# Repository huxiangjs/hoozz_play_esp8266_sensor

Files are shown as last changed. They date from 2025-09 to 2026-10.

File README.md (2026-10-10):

# Hoozz Play ESP8266 Sensor

Various sensors



## Sensor List

### (1) Temperature/Humidity/Brightness Sensor
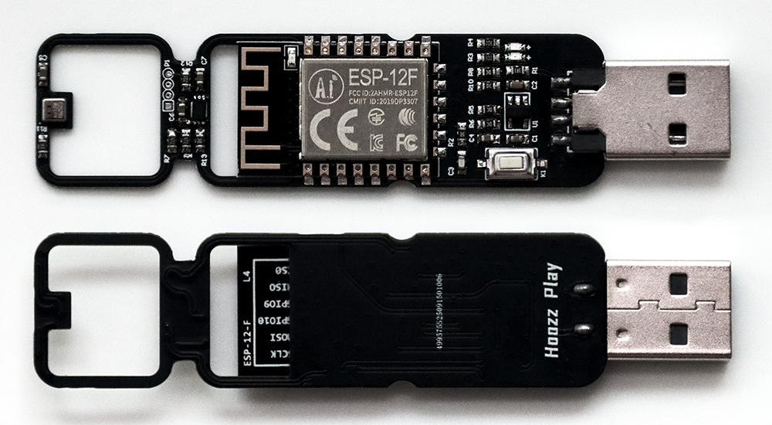
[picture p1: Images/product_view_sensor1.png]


### (2) tVOC/CO2eq Sensor
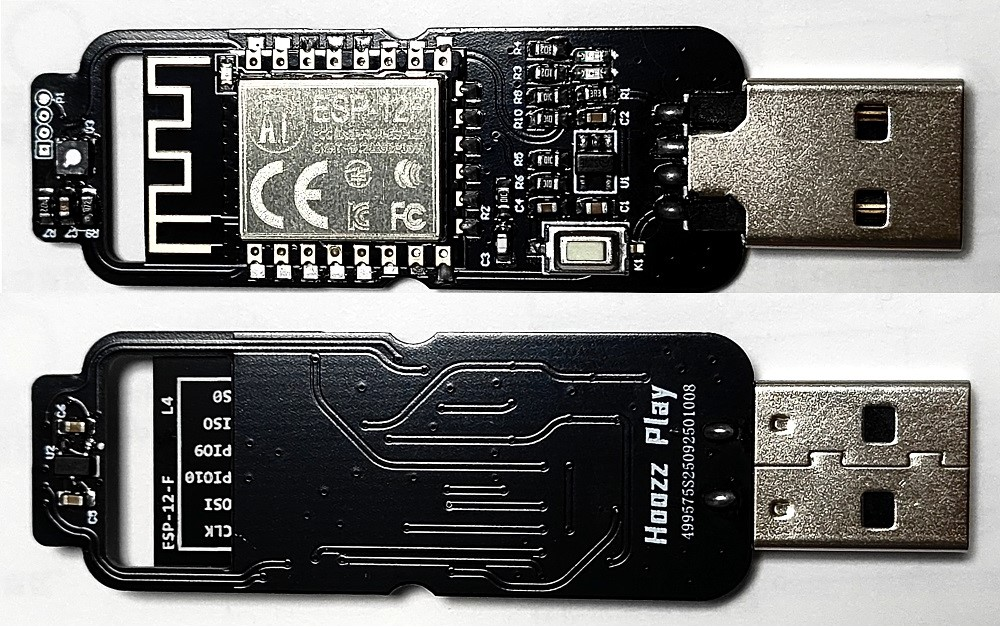
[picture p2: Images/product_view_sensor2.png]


## ESP8266_RTOS_SDK Version
```shell
$ git branch
* release/v3.3

$ git log --oneline | head -n 3
2bc42667 Merge branch 'bugfix/constrain_cryptography_v3.3' into 'release/v3.3'
4cab385e Tools: Constrain the cryptography package for avoiding breaking changes
6c438bce Merge branch 'bugfix/queue_arith_overflow_v3.3' into 'release/v3.3'

Toolchain version: crosstool-ng-1.22.0-100-ge567ec7b
Compiler version: 5.2.0
```

## Pull source code
```shell
git clone https://github.com/huxiangjs/hoozz_play_esp8266_sensor.git --recurse-submodules
```

## Build and Flash

* first step: open the sdkconfig file, modify `CONFIG_ESPTOOLPY_PORT` to your serial.

```shell
cd hoozz_play_esp8266_sensor/MCU
make -j$(nproc)
make flash
make monitor    # Monitor UART log output
```

## You can also directly burn the released bin file

1. Download the latest release zip package from the Releases column
2. Unzip the zip and you will see the following files:
   ```
   $ tree
   .
   |-- bootloader
   |   `-- bootloader.bin
   |-- partitions.bin
   `-- sensor.bin

   1 directory, 3 files
   ```
3. Open the latest official download tool `flash_download_tool` (official download address: [other-tools](https://www.espressif.com/en/support/download/other-tools))
4. Use the following options: (1) `Chip Type [ESP8266]`; (2) `WorkMode [Develop]`; (3) `LoadMode [UART]`;
5. Set the burn parameters according to the following table:

   |    Parameters  |     Value   |
   | :------------: | :---------: |
   | bootloader.bin | 0x0000      |
   | sensor.bin     | 0x10000     |
   | partitions.bin | 0x8000      |
   | SPI SPEED      | 40MHz       |
   | SPI MODE       | DIO         |
   | DoNotChgBin    | √           |
   | COM            | (Your port) |
   | BAUD           | 115200      |

6. Finally click **Start** to burn

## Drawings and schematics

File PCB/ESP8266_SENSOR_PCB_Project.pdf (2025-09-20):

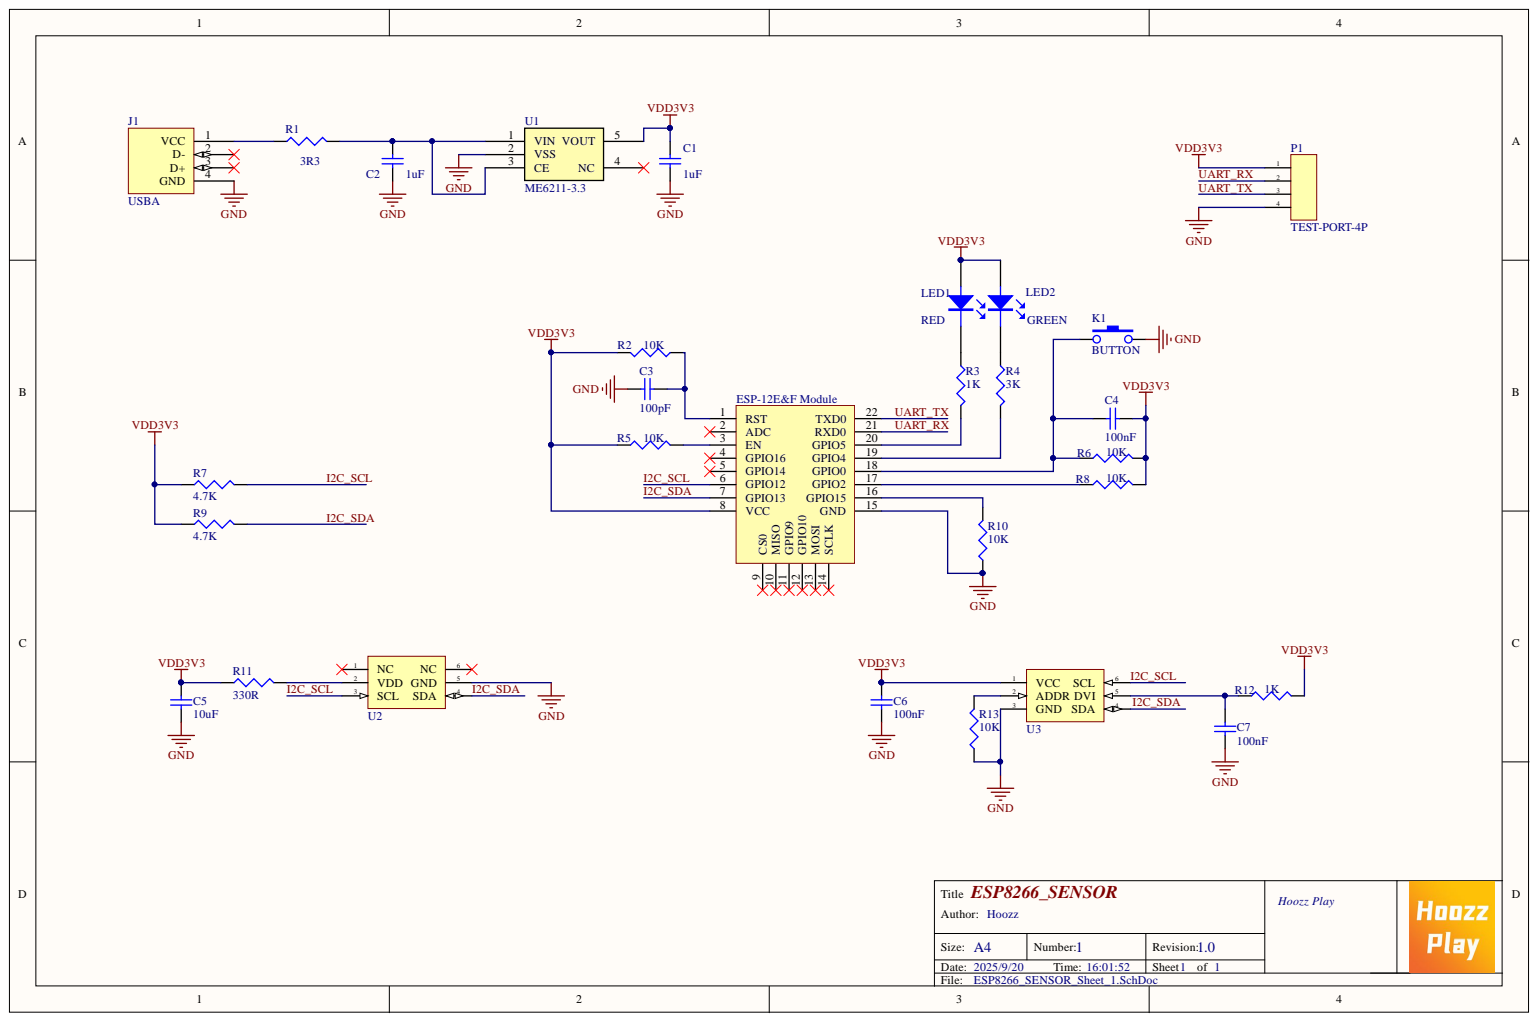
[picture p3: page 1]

ADC 2 | UART_RX

I2C_SCL | GPIO16 4

ESP8266_SENSOR Title Author: Hoozz | Hoozz Play

A4 Size: | 1 Number: | 1.0 Revision:
Date: 2025/9/20 Time: 16:01:52 | | Sheet 1 of 1

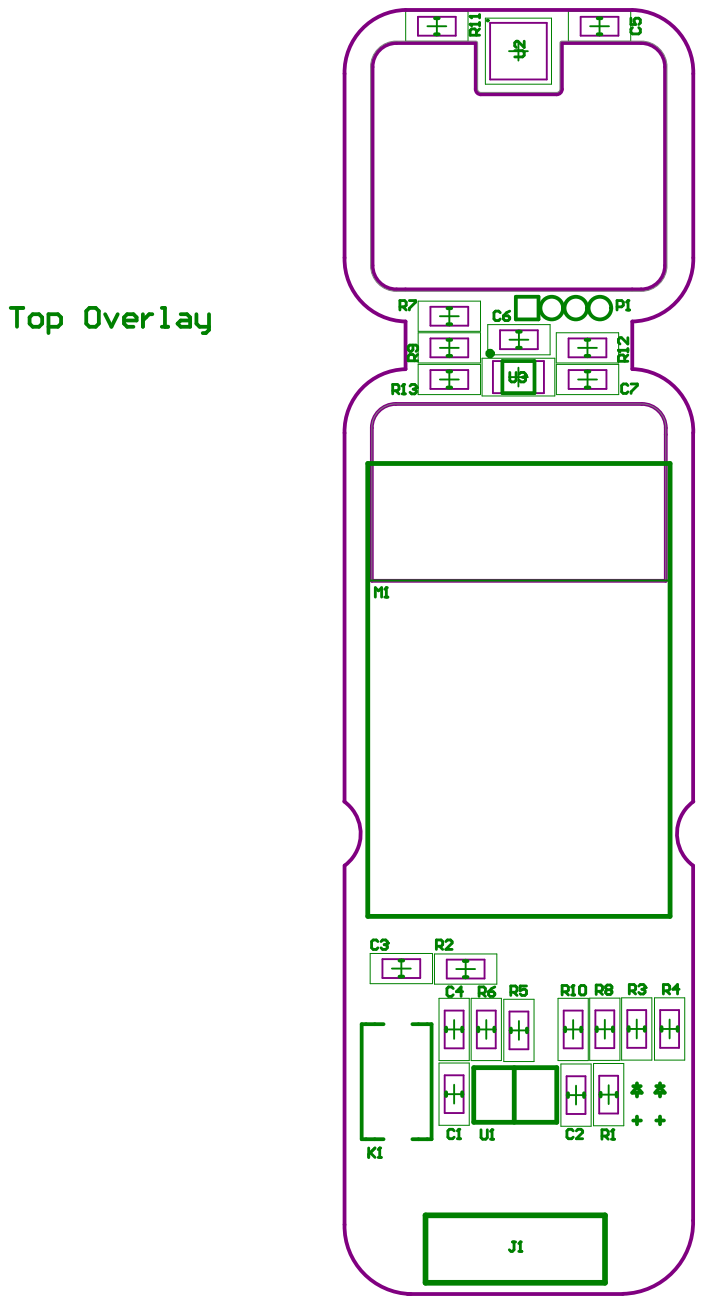
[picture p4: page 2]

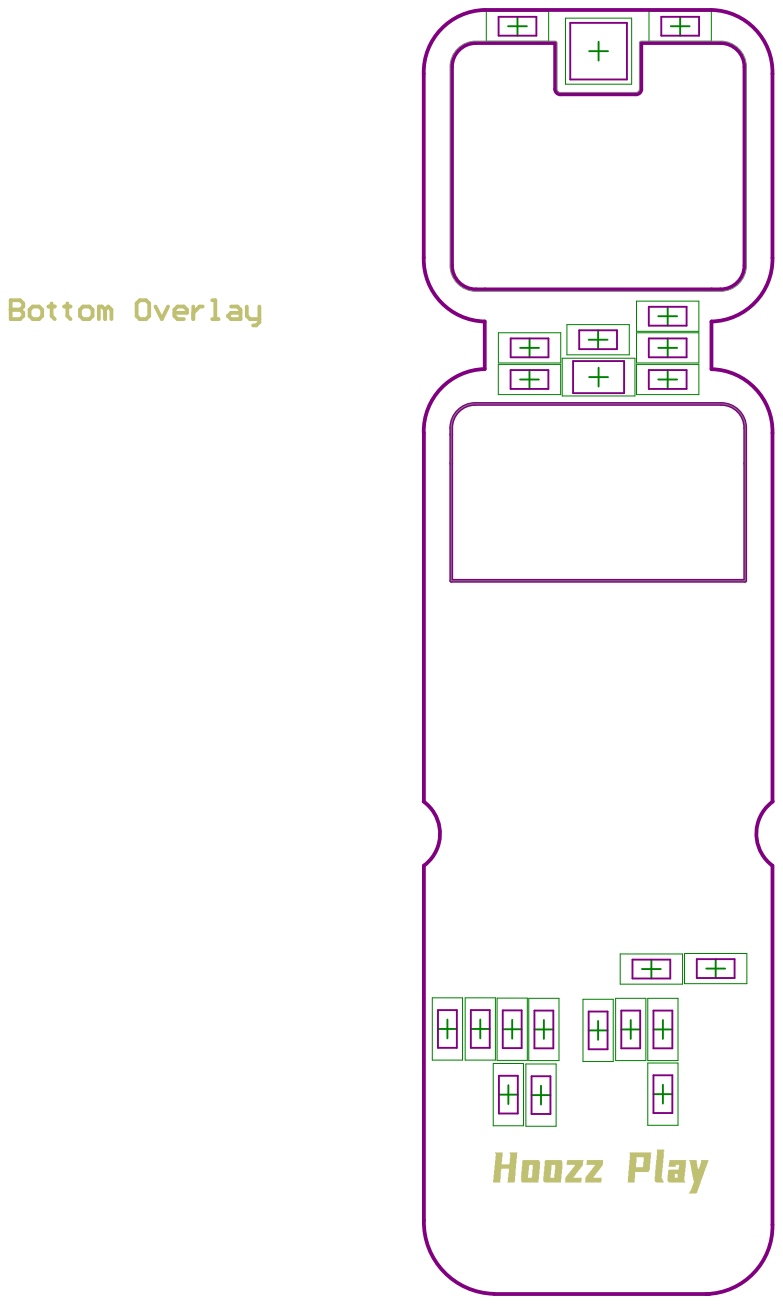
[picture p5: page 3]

Component list | Bill of Materials For Project [ESP8266_SENSOR_PCB_Project.PrjPCB] (No PCB Document Selected)
Source Data From: | | ESP8266_SENSOR_PCB_Project.PrjPCB
Project: | | ESP8266_SENSOR_PCB_Project.PrjPCB
Variant: | | None
Report Date: | 2025/9/20 | 16:01:57
Print Date: | 20-Sep-25 | 4:02:25 PM
# | Designator | Comment | Value | Footprint | Description | Pins | LibRef | Quantity

1 | J1 | USBA | | USB-A-2 | USB2.0 | 4 | USBA | 1
2 | P1 | TEST-PORT-4P | | TEST_PORT_4P | | 4 | TEST-PORT-4P | 1
3 | R1 | Res | 3R3 | 0603 | Resistor | 2 | Res | 1
4 | R2, R5, R6, R8, R10, R13 | Res | 10K | 0603 | Resistor | 2 | Res | 6
5 | R3, R12 | Res | 1K | 0603 | Resistor | 2 | Res | 2
6 | R4 | Res | 3K | 0603 | Resistor | 2 | Res | 1
7 | R7, R9 | Res | 4.7K | 0603 | Resistor | 2 | Res | 2
8 | R11 | Res | 330R | 0603 | Resistor | 2 | Res | 1
9 | LED1 | RED | | LED0603 | | 2 | LED | 1
10 | U1 | ME6211-3.3 | | SOT-23-5 | No Description Available | 5 | ME6211-3.3 | 1
11 | LED2 | GREEN | | LED0603 | | 2 | LED | 1
12 | M1 | ESP-12E&F Module | | ESP-12E&F Module | ESP-12E&F Module | 22 | ESP-12E&F Module | 1
13 | C1, C2 | Cap | 1uF | 0603 | Capacitor | 2 | Cap | 2
14 | C3 | Cap | 100pF | 0603 | Capacitor | 2 | Cap | 1
15 | C4, C6, C7 | Cap | 100nF | 0603 | Capacitor | 2 | Cap | 3
16 | C5 | Cap | 10uF | 0603 | Capacitor | 2 | Cap | 1
17 | K1 | BUTTON | | BUTTON | | 2 | BUTTON | 1
18 | U3 | BH1750 | | BH1750 | BH1750 | 6 | BH1750 | 1
19 | U2 | AHT20 | | AHT20 | AHT20 | 6 | AHT20 | 1
Approved | | | | Notes | | | | 29

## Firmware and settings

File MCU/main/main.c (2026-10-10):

/*
 * MIT License
 *
 * Copyright (c) 2025 huxiangjs
 *
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
 * THE SOFTWARE IS PROVIDED "AS IS", WITHOUT WARRANTY OF ANY KIND, EXPRESS OR
 * IMPLIED, INCLUDING BUT NOT LIMITED TO THE WARRANTIES OF MERCHANTABILITY,
 * FITNESS FOR A PARTICULAR PURPOSE AND NONINFRINGEMENT. IN NO EVENT SHALL THE
 * AUTHORS OR COPYRIGHT HOLDERS BE LIABLE FOR ANY CLAIM, DAMAGES OR OTHER
 * LIABILITY, WHETHER IN AN ACTION OF CONTRACT, TORT OR OTHERWISE, ARISING FROM,
 * OUT OF OR IN CONNECTION WITH THE SOFTWARE OR THE USE OR OTHER DEALINGS IN THE
 * SOFTWARE.
 */

#include <stdio.h>
#include <string.h>
#include <freertos/FreeRTOS.h>
#include <freertos/task.h>
#include <freertos/queue.h>
#include <esp_system.h>
#include <esp_spi_flash.h>
#include <esp_log.h>
#include <nvs_flash.h>

#include "event_bus.h"
#include "keyboard.h"
#include "store.h"
#include "simple_ctrl.h"
#include "wifi.h"
#include "gpio_led.h"
#include "i2c_bus.h"
#include "sensor_bh1750.h"
#include "sensor_aht20.h"
#include "sensor_sgp30.h"

static const char *TAG = "APP-MAIN";

#define ARRAY_SIZE(a)			(sizeof(a) / sizeof(a[0]))

#define KEYBOARD_GPIO_PIN		GPIO_NUM_0
#define LED_GREEN_GPIO_PIN		GPIO_NUM_4
#define LED_RED_GPIO_PIN		GPIO_NUM_5

#define I2C_BUS_SCL_PIN			GPIO_NUM_12
#define I2C_BUS_SDA_PIN			GPIO_NUM_13

#define LED_GREEN_BRIGHTNESS_MAX	64
#define LED_RED_BRIGHTNESS_MAX		128

#define SENSOR_TYPE_BRIGHTNESS		0x01
#define SENSOR_TYPE_HUMIDITY		0x02
#define SENSOR_TYPE_TEMPERATURE		0x03
#define SENSOR_TYPE_TVOC		0x04
#define SENSOR_TYPE_CO2EQ		0x05

#define SENSOR_CMD_GET_COUNT		0x00
#define SENSOR_CMD_GET_ITEM		0x01

#define SENSOR_RESULT_OK		0x00
#define SENSOR_RESULT_FAIL		0x01

#define SENSOR_NUM_MAX			5
#define SENSOR_NAME_LEN_MAX		32

static bool config_mode;
static QueueHandle_t led_queue;

static struct i2c_dev_init i2c_dev_list[] = {
	{ DEFAULT_BH1750_ADDR, "SENSOR-BH1750", sensor_bh1750_init, NULL },
	{ DEFAULT_AHT20_ADDR,  "SENSOR-AHT20",  sensor_aht20_init, NULL },
	{ DEFAULT_SGP30_ADDR,  "SENSOR-SGP30",  sensor_sgp30_init, NULL },
};

static uint32_t sensor_count;

struct sensor_info {
	uint8_t type;
	char name[SENSOR_NAME_LEN_MAX];
};

static struct sensor_info sensor_list[SENSOR_NUM_MAX];

static void app_show_info(void)
{
	int size = esp_get_free_heap_size();

	ESP_LOGI(TAG, "Free heap size: %dbytes", size);
}

static void print_chip_info(void)
{
	/* Print chip information */
	esp_chip_info_t chip_info;

	esp_chip_info(&chip_info);
	ESP_LOGI(TAG, "This is ESP8266 chip with %d CPU cores, WiFi, silicon revision %d, %dMB %s flash",
		 chip_info.cores, chip_info.revision, spi_flash_get_chip_size() / (1024 * 1024),
		 (chip_info.features & CHIP_FEATURE_EMB_FLASH) ? "embedded" : "external");
}

static void app_led_set_step(char step)
{
	xQueueSend(led_queue, (void *)&step, (TickType_t)0);
}

static int app_ctrl_request(char *buffer, int buf_offs, int vaild_size, int buff_size)
{
	uint32_t count;
	size_t len;

	if (vaild_size < 1) {
		ESP_LOGE(TAG, "Information command is incorrect");
		return -1;
	}

	if (buff_size - buf_offs < 2)
		goto nomem_err;

	switch (buffer[buf_offs]) {
	case SENSOR_CMD_GET_COUNT:		/* Get the number of sensors */
		if (buff_size - buf_offs < 6)
			goto nomem_err;
		buffer[buf_offs + 1] = SENSOR_RESULT_OK;
		buffer[buf_offs + 2] = (sensor_count >> 0) & 0xff;
		buffer[buf_offs + 3] = (sensor_count >> 8) & 0xff;
		buffer[buf_offs + 4] = (sensor_count >> 16) & 0xff;
		buffer[buf_offs + 5] = (sensor_count >> 24) & 0xff;
		return 6;
	case SENSOR_CMD_GET_ITEM:		/* Get sensor information */
		if (vaild_size != 5)
			goto lllegal_err;
		if (buff_size - buf_offs < 2 + 2 + SENSOR_NAME_LEN_MAX)
			goto nomem_err;
		count = (buffer[buf_offs + 1] << 0) |
			(buffer[buf_offs + 2] << 8) |
			(buffer[buf_offs + 3] << 16) |
			(buffer[buf_offs + 4] << 24);
		len = 0;
		if (count >= SENSOR_NUM_MAX) {
			buffer[buf_offs + 1] = SENSOR_RESULT_FAIL;
			ESP_LOGE(TAG, "Get failed, count incorrect");
		} else {
			buffer[buf_offs + 2] = sensor_list[count].type;
			buffer[buf_offs + 3] = 0;	/* Only one sensor */
			len = strlen(sensor_list[count].name);
			memcpy(buffer + buf_offs + 2 + 2, sensor_list[count].name, len);
			buffer[buf_offs + 1] = SENSOR_RESULT_OK;
			len += 2;
		}
		return 2 + len;
	default:
		goto lllegal_err;
	}

	return 0;
nomem_err:
	ESP_LOGE(TAG, "Not enough buffer space");
	return -1;
lllegal_err:
	ESP_LOGE(TAG, "Lllegal command");
	return -1;
}

static void app_led_task(void *arg)
{
	TickType_t xTicksToWait = portMAX_DELAY;
	char step;
	uint8_t red_value = 0;
	uint8_t green_value = 0;
	bool is_green = false;
	char recyclable_step = 0;

	while(1) {
		xQueueReceive(led_queue, &step, xTicksToWait);
		switch (step) {
		case 'r':
			xTicksToWait = portMAX_DELAY;
			green_value = 0;
			red_value = LED_RED_BRIGHTNESS_MAX;
			is_green = false;
			recyclable_step = step;
			break;
		case 'g':
			xTicksToWait = pdMS_TO_TICKS(10000);;
			red_value = 0;
			green_value = LED_GREEN_BRIGHTNESS_MAX;
			is_green = true;
			recyclable_step = step;
			step = 'P';
			break;
		case 'C':
			xTicksToWait = pdMS_TO_TICKS(100);
			red_value = red_value ? 0 : LED_RED_BRIGHTNESS_MAX;
			green_value = red_value ? 0 : LED_GREEN_BRIGHTNESS_MAX;
			recyclable_step = step;
			break;
		case 'P':
			xTicksToWait = portMAX_DELAY;
			green_value = 0;
			recyclable_step = step;
			break;
		case (char)-'P':
			recyclable_step = step;
			if (is_green) {
				xTicksToWait = 0;
				step = 'g';
			} else {
				xTicksToWait = portMAX_DELAY;
			}
			break;
		case 'F':
			gpio_led_set_red_brightness(LED_RED_BRIGHTNESS_MAX);
			gpio_led_set_green_brightness(0);
			vTaskDelay(pdMS_TO_TICKS(40));
			gpio_led_set_red_brightness(0);
			gpio_led_set_green_brightness(LED_GREEN_BRIGHTNESS_MAX);
			vTaskDelay(pdMS_TO_TICKS(40));
			step = recyclable_step;
			break;
		default:
			ESP_LOGW(TAG, "unknow step: %d", step);
		}
		gpio_led_set_red_brightness(red_value);
		gpio_led_set_green_brightness(green_value);
	}

	vQueueDelete(led_queue);
	vTaskDelete(NULL);
}

static bool app_event_notify_callback(struct event_bus_msg *msg)
{
	char buffer[4];

	switch (msg->type) {
	case EVENT_BUS_STARTUP:
		app_led_set_step('r');
		break;
	case EVENT_BUS_WIFI_CONNECTED:
		app_led_set_step('g');
		break;
	case EVENT_BUS_WIFI_DISCONNECTED:
		app_led_set_step('r');
		break;
	case EVENT_BUS_START_SMART_CONFIG:
		app_led_set_step('C');
		break;
	case EVENT_BUS_STOP_SMART_CONFIG:
		config_mode = false;
		break;
	case EVENT_BUS_KEYBOARD:
		if (config_mode || msg->param1 != KEYBOARD_GPIO_PIN)
			break;
		if ((msg->param2 == KEYBOARD_EVENT_SHORT_RELEASE)) {
			// ESP_LOGW(TAG, "Restarting now");
			// fflush(stdout);
			// esp_restart();
			app_led_set_step(-'P');
		}
		/* Smart config */
		if (msg->param2 == KEYBOARD_EVENT_LONG_RELEASE) {
			ESP_LOGI(TAG, "Smart config");
			wifi_smartconfig();
			config_mode = true;
		}
		break;
	case EVENT_BUS_SENSOR_BRIGHTNESS_UPDATED:
		buffer[0] = SENSOR_TYPE_BRIGHTNESS;
		buffer[1] = (char)msg->param1;
		buffer[2] = (char)((msg->param2 >> 0) & 0xff);
		buffer[3] = (char)((msg->param2 >> 8) & 0xff);
		simple_ctrl_notify(buffer, sizeof(buffer));
		break;
	case EVENT_BUS_SENSOR_HUMIDITY_UPDATED:
		buffer[0] = SENSOR_TYPE_HUMIDITY;
		buffer[1] = (char)msg->param1;
		buffer[2] = (char)((msg->param2 >> 0) & 0xff);
		buffer[3] = (char)((msg->param2 >> 8) & 0xff);
		simple_ctrl_notify(buffer, sizeof(buffer));
		break;
	case EVENT_BUS_SENSOR_TEMPERATURE_UPDATED:
		buffer[0] = SENSOR_TYPE_TEMPERATURE;
		buffer[1] = (char)msg->param1;
		buffer[2] = (char)((msg->param2 >> 0) & 0xff);
		buffer[3] = (char)((msg->param2 >> 8) & 0xff);
		simple_ctrl_notify(buffer, sizeof(buffer));
		break;
	case EVENT_BUS_SENSOR_TVOC_UPDATED:
		buffer[0] = SENSOR_TYPE_TVOC;
		buffer[1] = (char)msg->param1;
		buffer[2] = (char)((msg->param2 >> 0) & 0xff);
		buffer[3] = (char)((msg->param2 >> 8) & 0xff);
		simple_ctrl_notify(buffer, sizeof(buffer));
		break;
	case EVENT_BUS_SENSOR_CO2EQ_UPDATED:
		buffer[0] = SENSOR_TYPE_CO2EQ;
		buffer[1] = (char)msg->param1;
		buffer[2] = (char)((msg->param2 >> 0) & 0xff);
		buffer[3] = (char)((msg->param2 >> 8) & 0xff);
		simple_ctrl_notify(buffer, sizeof(buffer));
		break;
	}

	return false;
}

void app_main(void)
{
	struct event_bus_msg msg = { EVENT_BUS_STARTUP, 0, 0};
	uint8_t keyboard_gpios[] = { KEYBOARD_GPIO_PIN };

	print_chip_info();
	app_show_info();

	/* GPIO LED */
	gpio_led_init(LED_RED_GPIO_PIN, LED_GREEN_GPIO_PIN);
	led_queue = xQueueCreate(10, sizeof(char));
	ESP_ERROR_CHECK(led_queue == NULL);
	ESP_ERROR_CHECK(xTaskCreate(app_led_task, "app_led_task", 1024,
			NULL, tskIDLE_PRIORITY + 2, NULL) != pdPASS);

	/* NVS init */
	ESP_ERROR_CHECK(nvs_flash_init());

	/* install gpio isr service */
	ESP_ERROR_CHECK(gpio_install_isr_service(0));

	store_init();

	/* Event bus */
	event_bus_init();
	event_bus_register(app_event_notify_callback);
	event_bus_send(&msg);

	/* Keyboard */
	keyboard_init(keyboard_gpios, sizeof(keyboard_gpios));

	/* Wifi */
	wifi_init();

	/* Network ctrl */
	simple_ctrl_init("SENSOR");
	simple_ctrl_set_class_id(CLASS_ID_SENSOR);
	simple_ctrl_request_register(app_ctrl_request);

	/* Sensor */
	i2c_bus_init(I2C_BUS_SDA_PIN, I2C_BUS_SCL_PIN, i2c_dev_list, ARRAY_SIZE(i2c_dev_list));

	if (sensor_bh1750_is_active()) {
		sensor_list[sensor_count].type = SENSOR_TYPE_BRIGHTNESS;
		strncpy(sensor_list[sensor_count].name, "Brightness",
			sizeof(sensor_list[sensor_count].name));
		sensor_count++;
		ESP_LOGI(TAG, "Sensor: brightness ready");
	}
	if (sensor_aht20_is_active()) {
		sensor_list[sensor_count].type = SENSOR_TYPE_HUMIDITY;
		strncpy(sensor_list[sensor_count].name, "Humidity",
			sizeof(sensor_list[sensor_count].name));
		sensor_count++;
		ESP_LOGI(TAG, "Sensor: humidity ready");

		sensor_list[sensor_count].type = SENSOR_TYPE_TEMPERATURE;
		strncpy(sensor_list[sensor_count].name, "Temperature",
			sizeof(sensor_list[sensor_count].name));
		sensor_count++;
		ESP_LOGI(TAG, "Sensor: temperature ready");
	}
	if (sensor_sgp30_is_active()) {
		sensor_list[sensor_count].type = SENSOR_TYPE_TVOC;
		strncpy(sensor_list[sensor_count].name, "tVOC",
			sizeof(sensor_list[sensor_count].name));
		sensor_count++;
		ESP_LOGI(TAG, "Sensor: tVOC ready");

		sensor_list[sensor_count].type = SENSOR_TYPE_CO2EQ;
		strncpy(sensor_list[sensor_count].name, "CO2eq",
			sizeof(sensor_list[sensor_count].name));
		sensor_count++;
		ESP_LOGI(TAG, "Sensor: CO2eq ready");
	}

	wifi_connect();

	app_show_info();
}

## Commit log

2025-08-09 Initialize the basic project files
    [partitions.csv]
2025-08-09 Improve protocols and drivers
2025-09-18 Using the new AHT20 driver
2025-09-20 Add PCB file
    [ESP8266_SENSOR_PCB_1.PcbDoc, ESP8266_SENSOR_PCB_Project.PrjPCB, ESP8266_SENSOR_Sheet_1.SchDoc]
2026-07-04 Fixed an issue where the client might not be able to read sensor list
    [main.c]
2026-10-09 Add SGP30 sensor support
2026-11-08 Add the missing tVOC/CO2eq Sensor PCB file
2026-11-14 CI: trim whitespace from the project name before writing ota_file
    The Makefile uses 'PROJECT_NAME := <name>' so the awk extraction
    carries a leading space into the ota_file content (the unquoted zip
    argument dropped it, the quoted echo did not). Strip spaces and
    carriage returns so ota_file holds the bare bin name.
2026-11-14 Add OTA firmware update support
    Port the OTA feature from hoozz_play_esp8266_smart_ir:
    - main.c: report the build info (git branch/sha/dirty + SDK version)
    and enable OTA with the "hoozz" tcp_crypto transport after NVS
    init
    - add the ota/ota_flash/tcp_crypto/tiny-AES-c source stubs (the OTA
    core and its encrypted tunnel live in esp32-common)
    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
2026-11-14 Stop the sensor tasks before the OTA reboot to avoid I2C bus lockup
    A warm reboot (esp_restart) does not fully reset the I2C bus: restarting
    with an I2C transaction in progress can leave the bus locked. Before OTA
    the device only ever had cold boots, so this never showed up.
    Register a pre-restart callback (the new ota_enable() parameter) that
    stops all the sensor polling tasks via the new i2c_bus_stop() before the
    transfer task reboots the chip into the new image.
    Bumps the submodules:
    - esp32-common: ota_enable()/simple_ctrl_ota_enable() take a
    pre-restart callback (c7e0843)
    - esp8266-common: i2c_bus_stop() + the drivers' stop()/is_active()
    callbacks (b8affe1)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
